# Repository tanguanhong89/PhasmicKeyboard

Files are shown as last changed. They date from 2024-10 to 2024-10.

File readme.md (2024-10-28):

# 1. Overview
Modular keyboard with adjustable key positions.

Uses `keebio/nyquist/rev3` vial keymap. 

## 1.1. Ortholinear mode
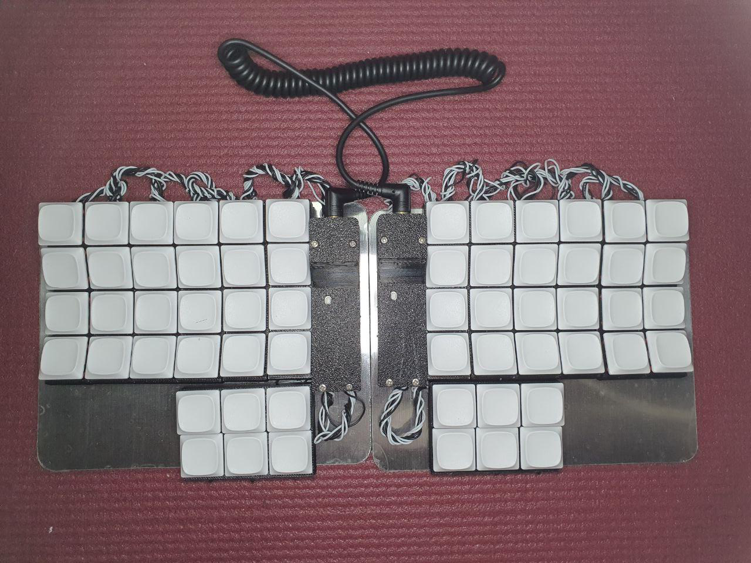
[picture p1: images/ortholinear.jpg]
Title


## 1.2. Column stagger mode
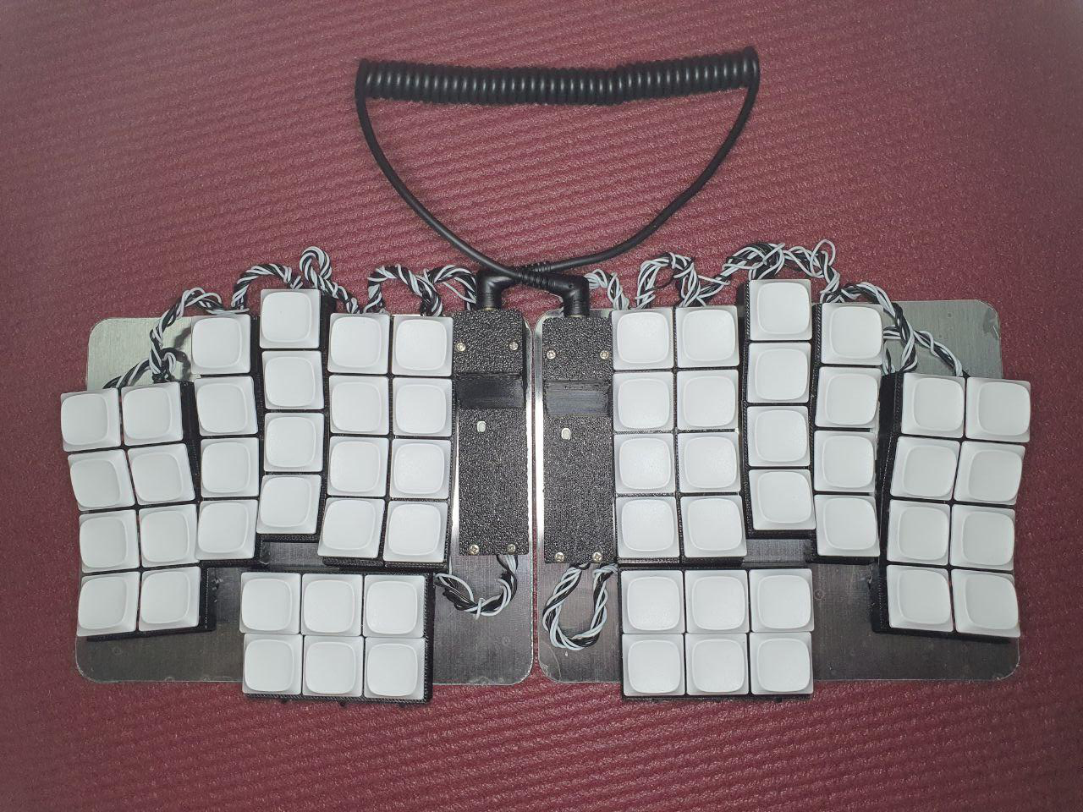
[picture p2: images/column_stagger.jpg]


## 1.3. WASD mode
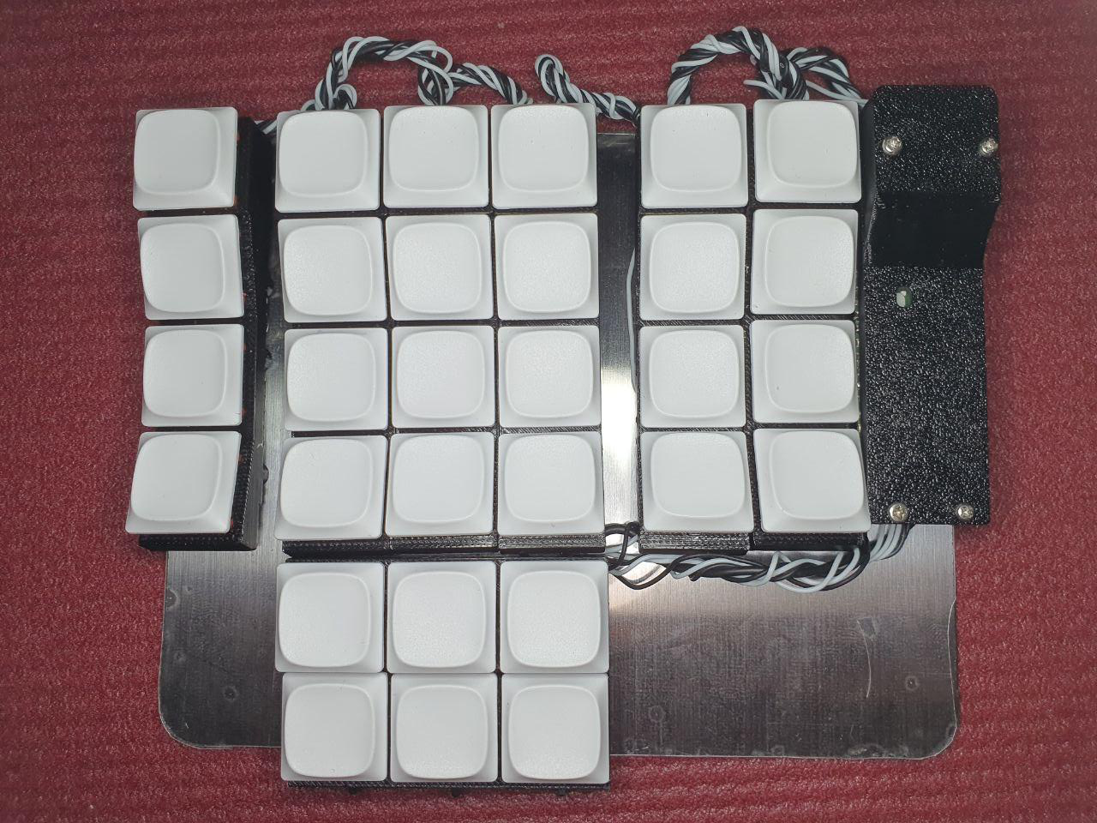
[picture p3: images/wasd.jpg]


## 1.4. Thumb cluster slide switches

So as to allow for toggling of those last 3 thumb cluster keys
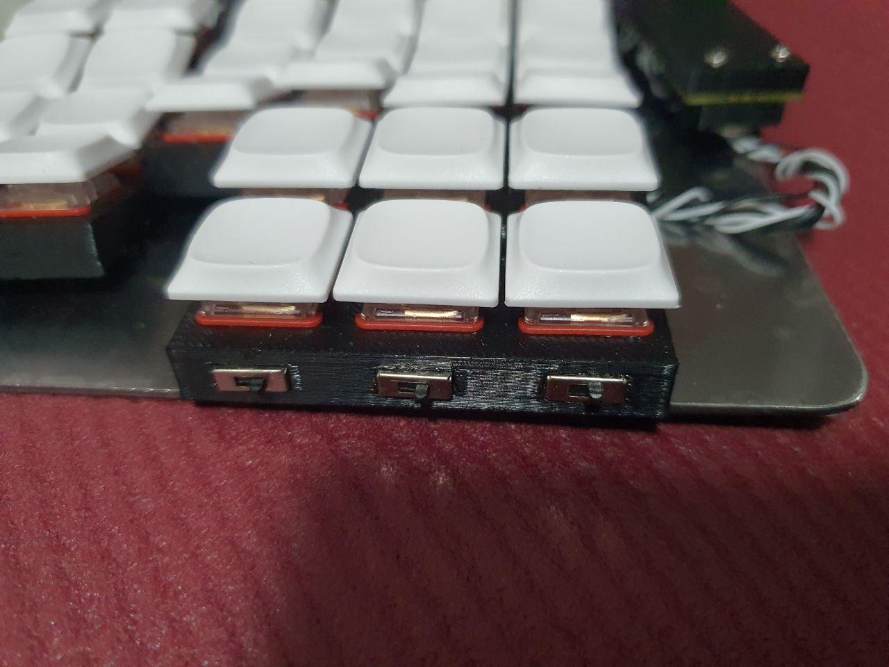
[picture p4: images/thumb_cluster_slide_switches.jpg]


## 1.5. Tilted column keys
2nd and 4th rows have 15 degrees tilted keys. This is for easier touch typing navigation along the y axis.
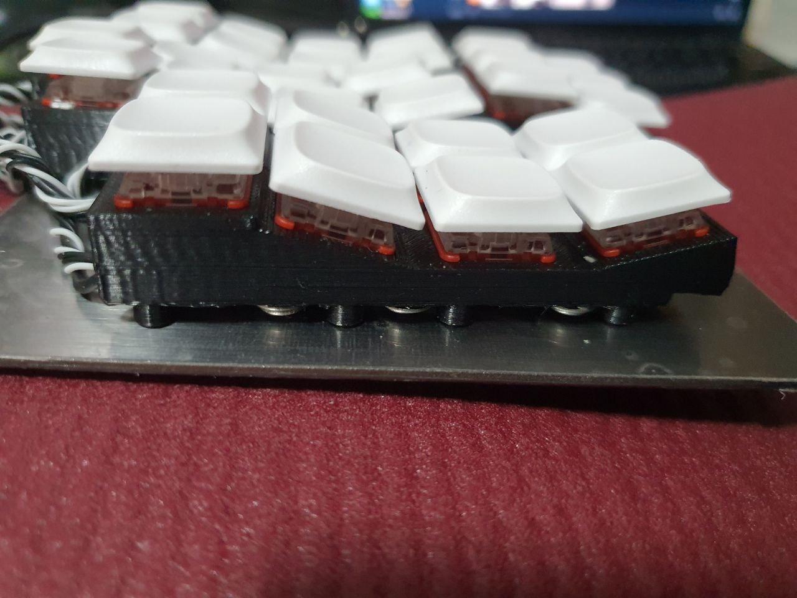
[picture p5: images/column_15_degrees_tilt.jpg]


## 1.6. Tenting with magnets
Additional magnets can be used for tenting the keyboard.
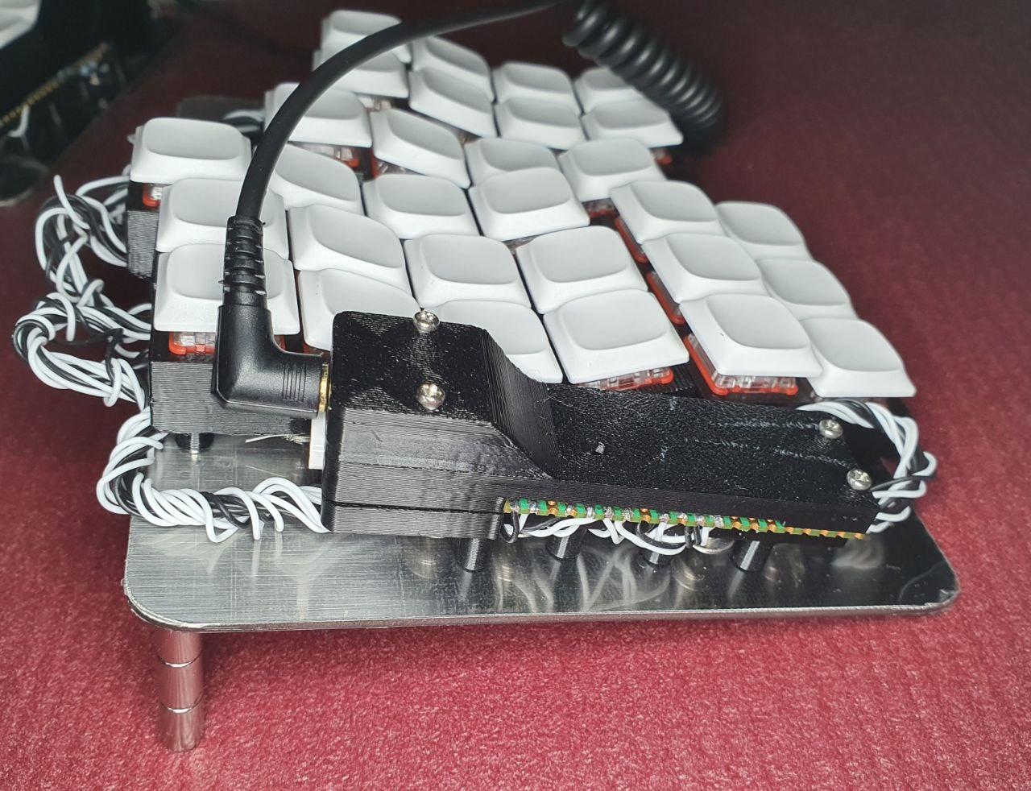
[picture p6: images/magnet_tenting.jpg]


# 2. Bill of materials
## 2.1. 3D models
- Column x 12
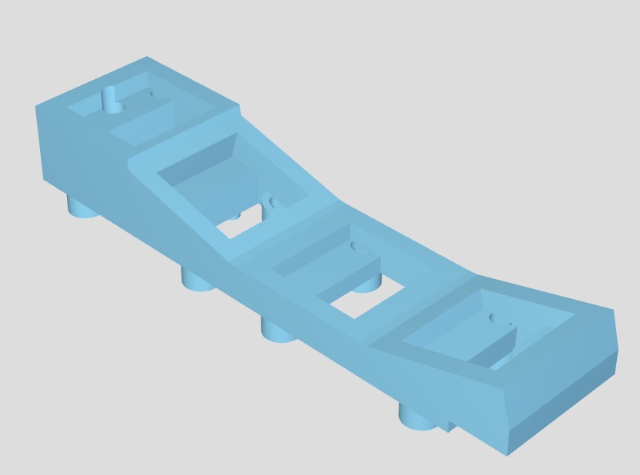
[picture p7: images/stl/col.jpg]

[An Internal Link](/stl/col.stl)
- Thumb cluster x 2
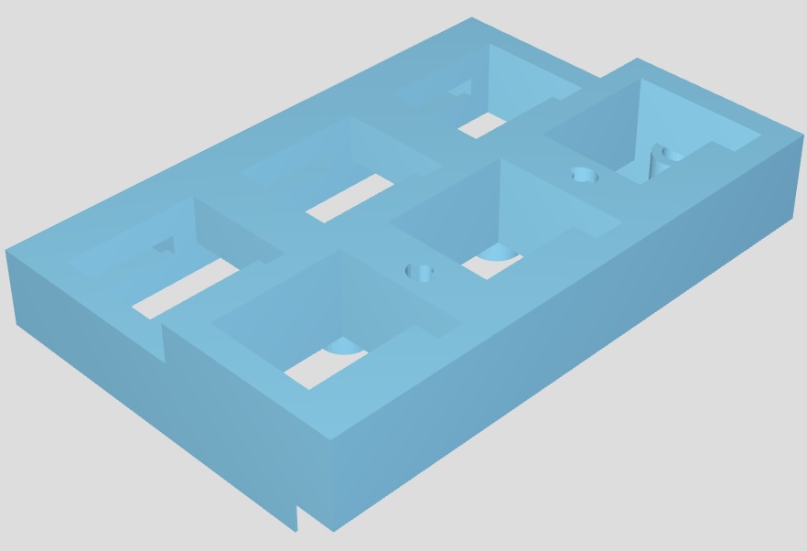
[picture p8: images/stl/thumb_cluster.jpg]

[An Internal Link](stl/thumb_cluster_2x3.stl)
- RP2040 pico housing bottom x 2
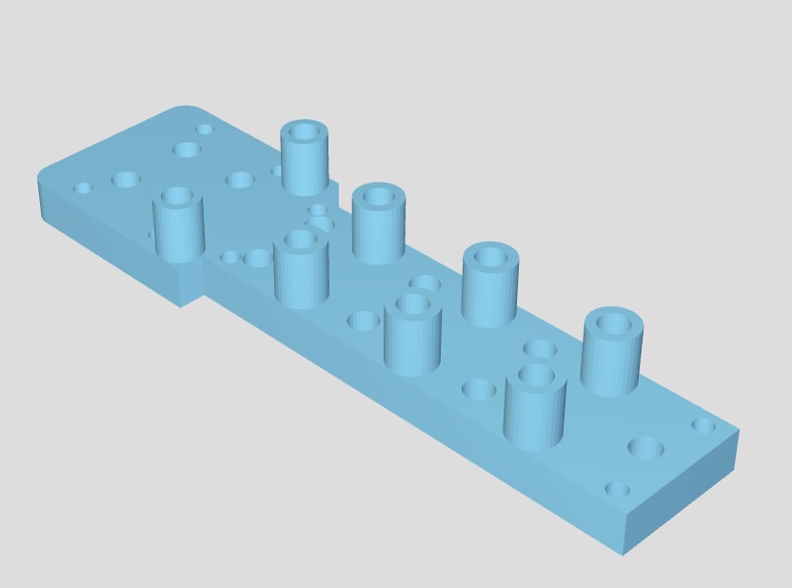
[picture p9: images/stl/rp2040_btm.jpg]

[An Internal Link](/stl/rp2040_pico_housing_btm.stl)
- RP2040 pico housing top x 2
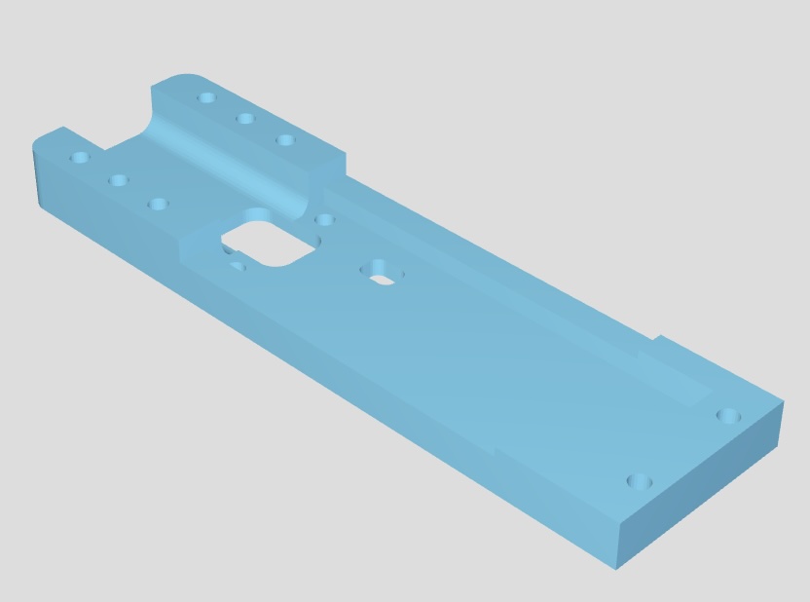
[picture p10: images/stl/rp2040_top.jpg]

[An Internal Link](/stl/rp2040_pico_housing_top.stl)
- RP2040 pico housing bottom x 2
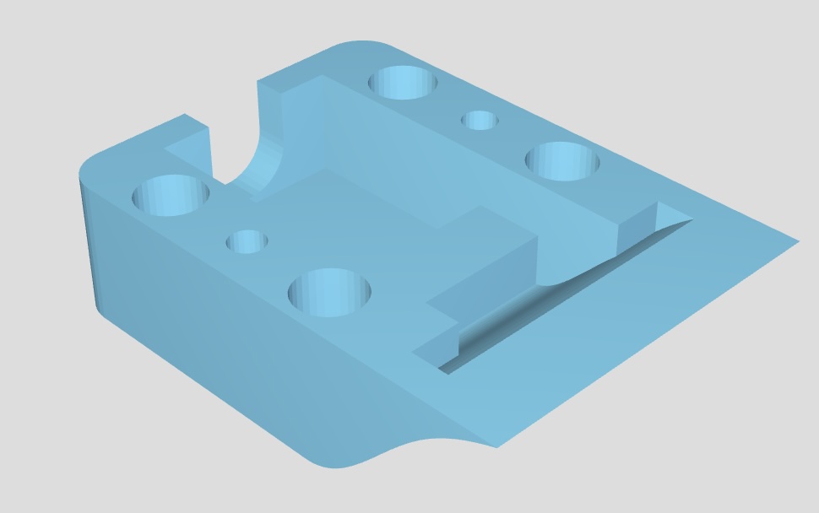
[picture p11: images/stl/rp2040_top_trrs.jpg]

[An Internal Link](/stl/rp2040_pico_housing_top_trrs.stl)

## 2.2. Others
- 124 x 
    - M3 screw x 5mm(threads)
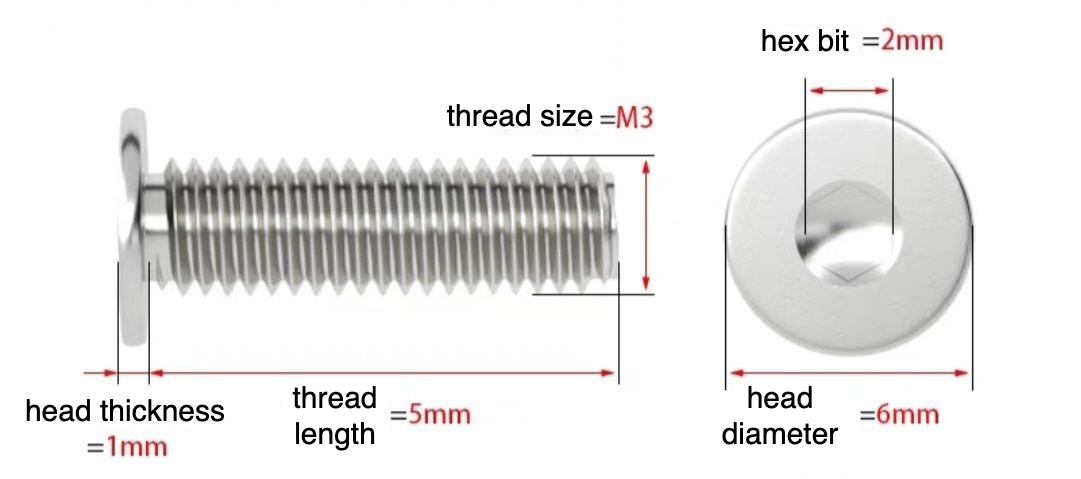
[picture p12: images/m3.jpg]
    
    - M3 washer x 8mm(radius) x 0.5mm(thickness)
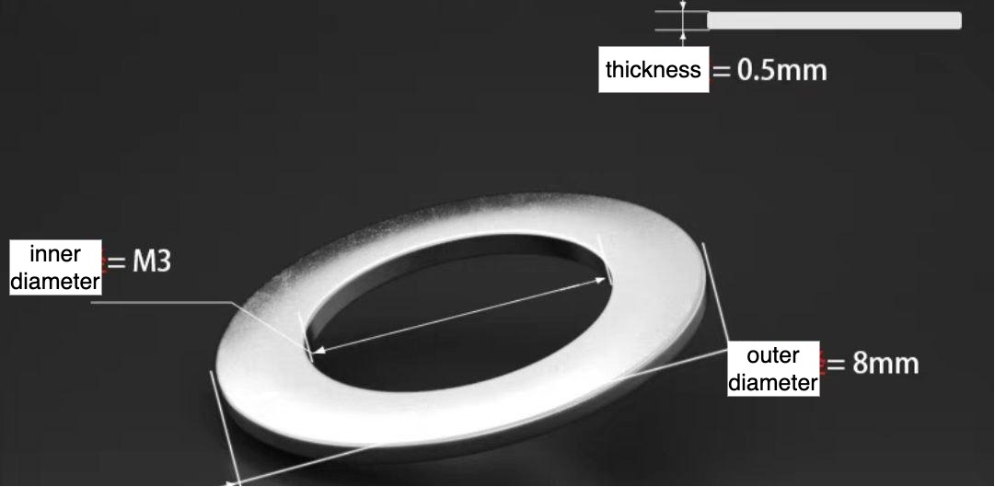
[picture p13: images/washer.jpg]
    

    Breakdown
    - 7(per column)x12(columns) +
    - 11(per rp2040 housing) x2(rp2040 housing) +
    - 9 (thumb cluster) x2(thumb cluster)

- 124 x magnets cylindrical N52 grade 3mm x 3mm
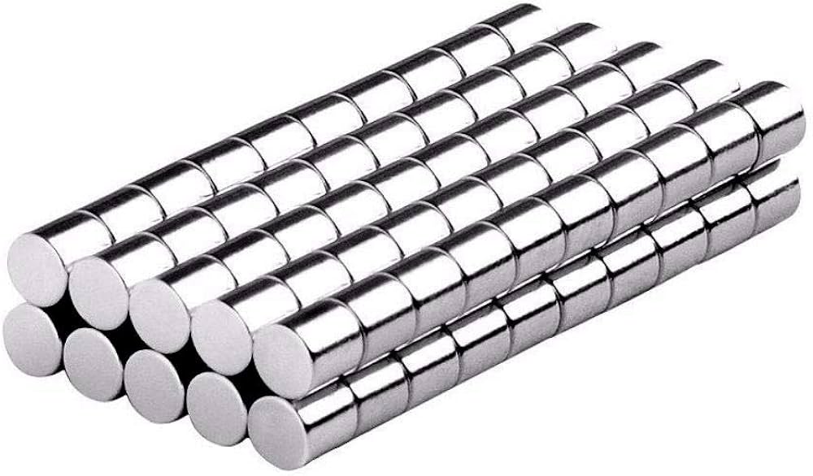
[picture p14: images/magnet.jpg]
    
- 60 x kailh choc v1 switches
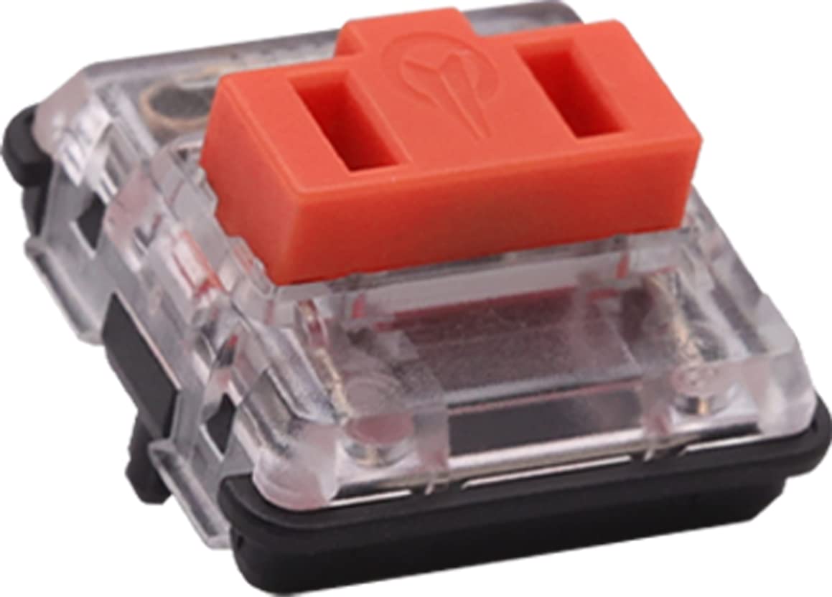
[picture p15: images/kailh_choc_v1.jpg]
    
- 60 x Geekark low profile keycaps for kailh choc v1 switches
    
- 60 x 1n4148 diodes
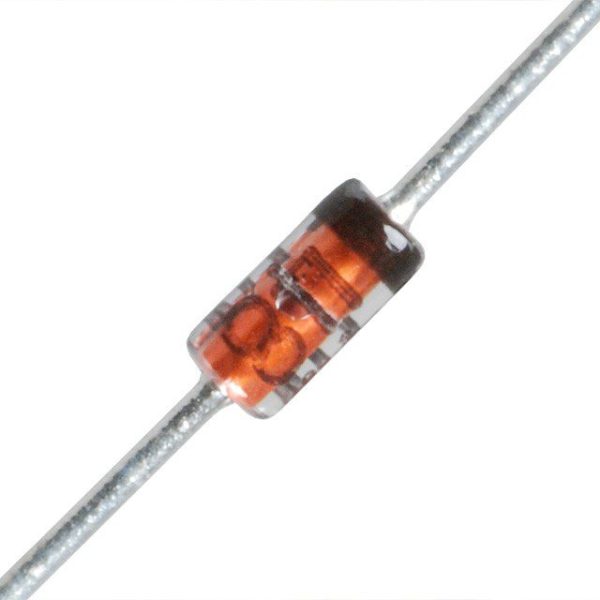
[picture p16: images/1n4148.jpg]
    
- 16 x M2 x 6mm (preferably torx)
- 4 x M2 x 10mm (preferably torx)
- 6 x SS12D00 (optional)
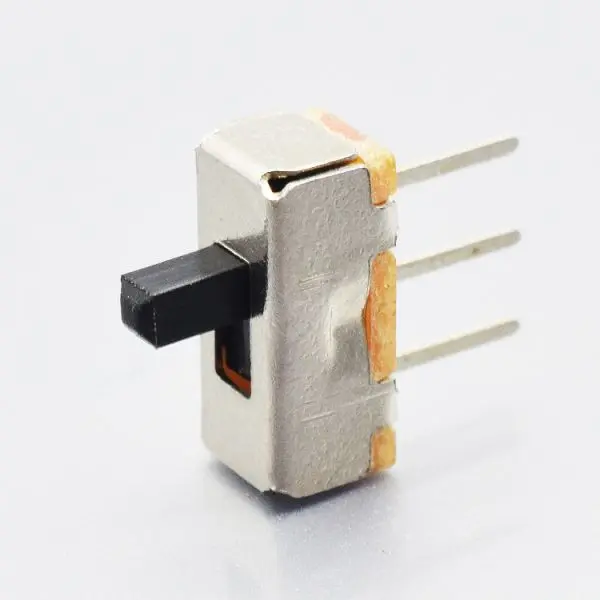
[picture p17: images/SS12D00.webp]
    
- 2 x RP2040 pico
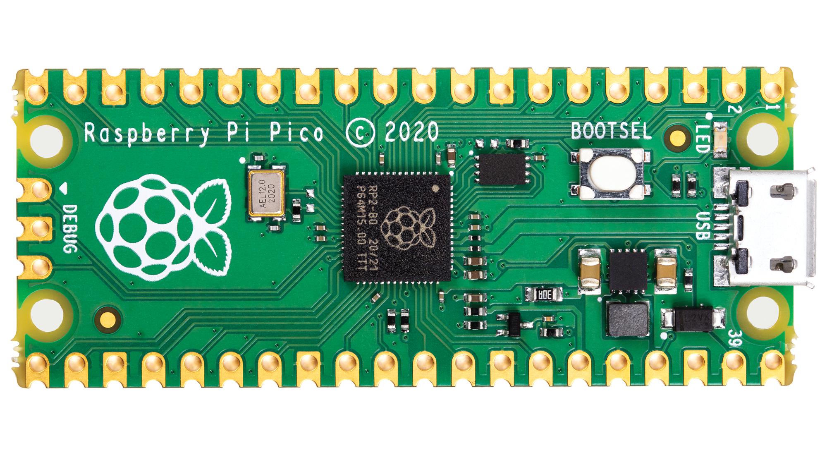
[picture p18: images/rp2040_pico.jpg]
    
- 2 x usb-c to micro-usb adapter
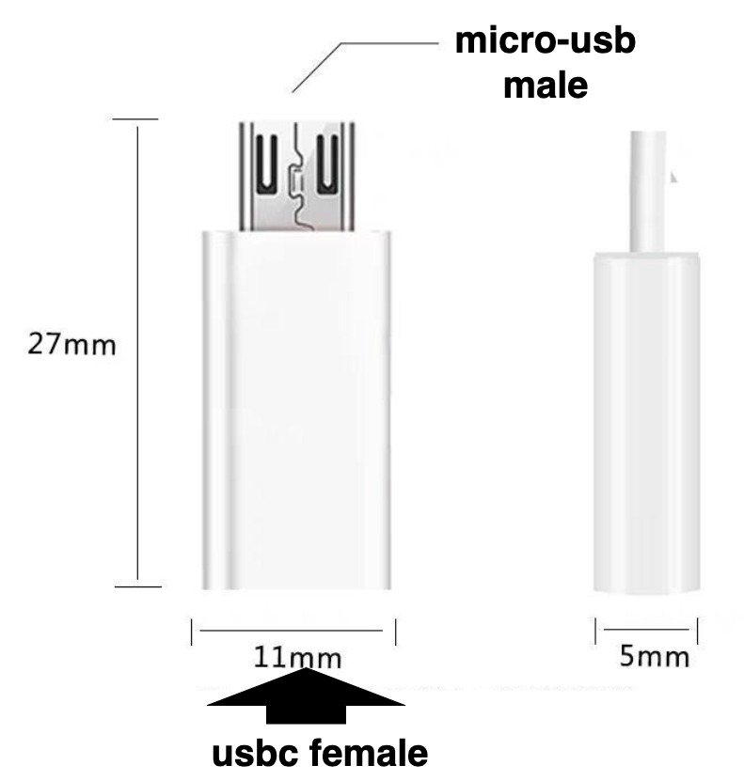
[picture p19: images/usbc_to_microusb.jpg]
    
- 2 x 430 grade steel plates(150mm x 120mm x 1.5mm thick)
- 1 x anti shatter film (to cover the steel plates)
- 1 x TRRS cable
- 1 x resistor (1kΩ-100kΩ range)
- 30 AUG wires (preferably more than 2 colors)
- 24 AUG wire (single color is enough)

# 3. Assembly
## 3.1. Fastening wires
One of the more efficient way to secure wire is to insert it through the M3 washer from 1 direction, then M3 screw from the opposite direction as shown below
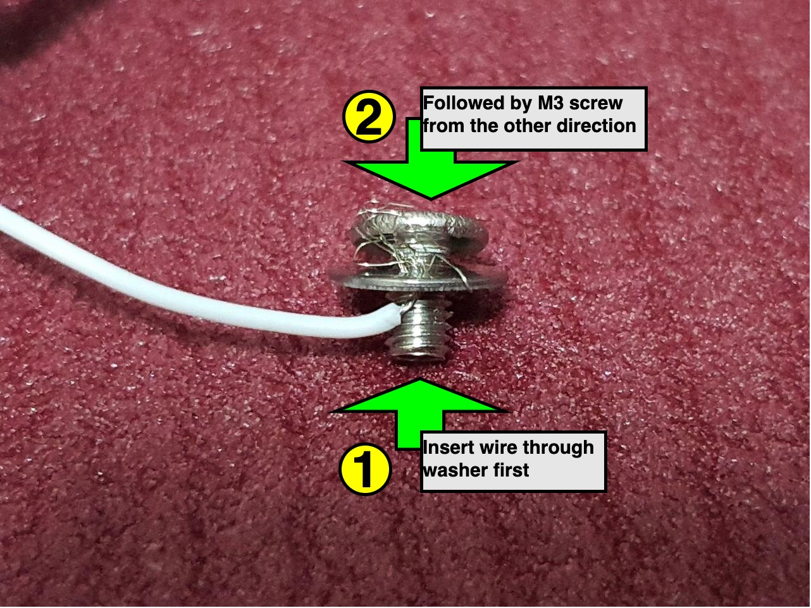
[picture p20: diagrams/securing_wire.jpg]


## 3.2. Preparing switches
48 switches are soldered with copper wires on the left pin. These switches are for the columns
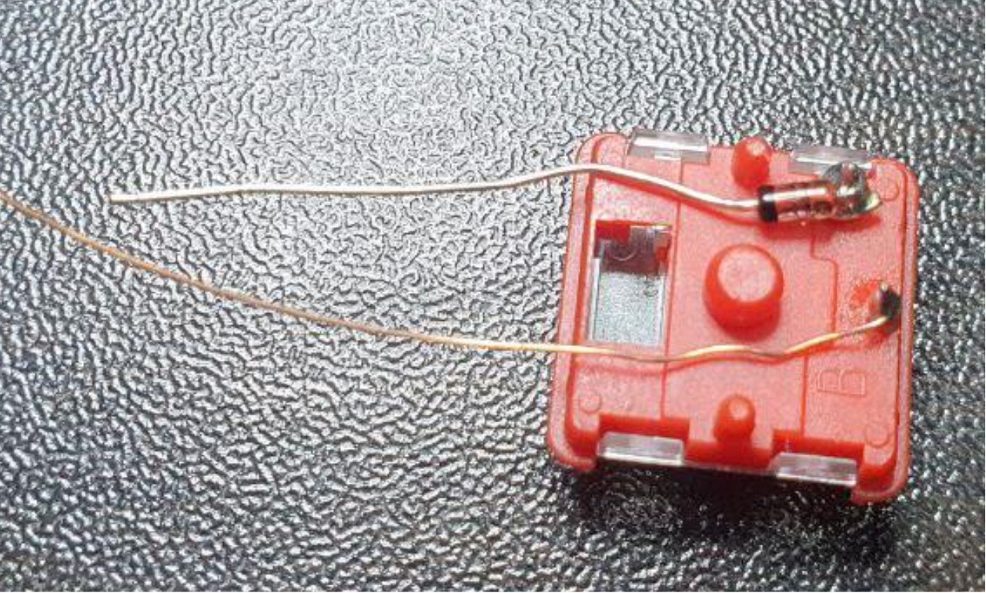
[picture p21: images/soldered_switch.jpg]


The remaining 12 switches are **soldered with 30 AUG insulated wires on the left pin** instead.

TODO add image

All switches are soldered with 1 1n4148 diode on the right pin, note the diode direction.
## 3.3. Magnets
Insert magnets with same facing poles into 3d printed parts on the same side (eg. all downward facing North pole to be on the left side of each column)

Repeat with opposite side with opposite facing pole

## 3.4. 430 Grade steel plates lamination
Laminating steel plates is not necessary, but recommended to ensure magnets slide smoothly on the plates, and also to prevent scratching and rust.

Cut the anti-shatter film by tracing loosely, the outline of the metal plate, with a pen knife.
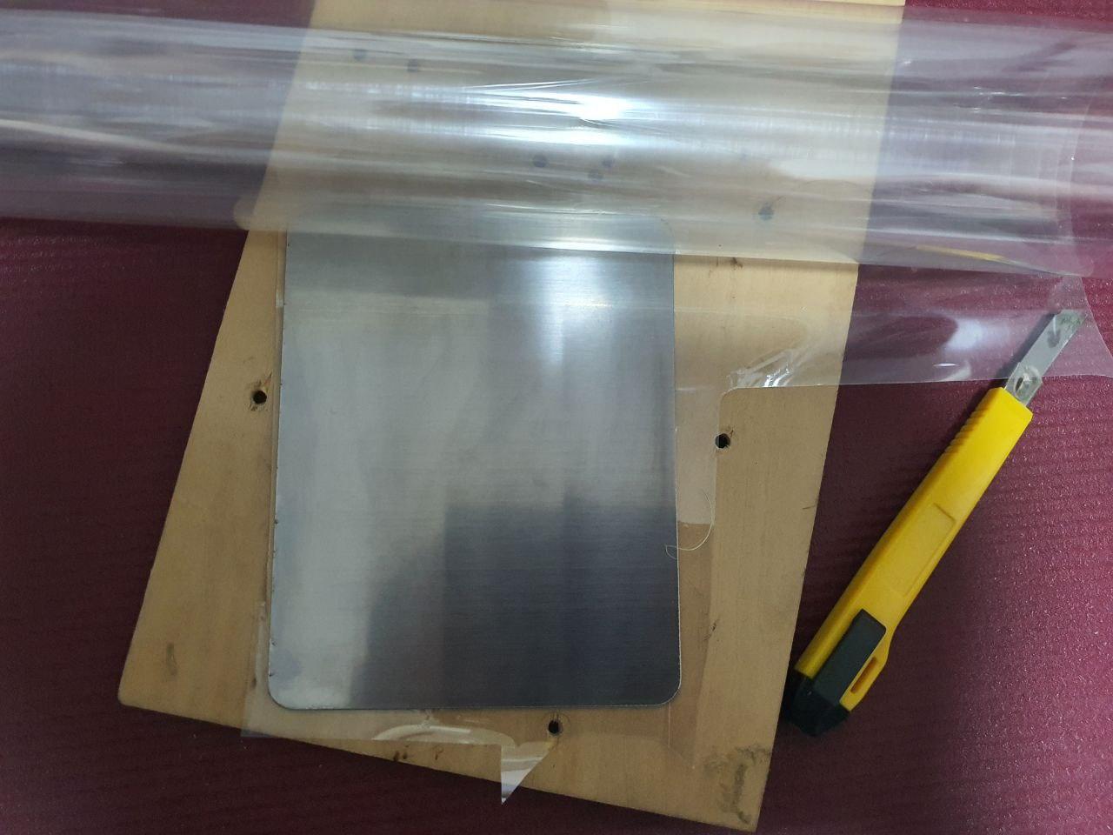
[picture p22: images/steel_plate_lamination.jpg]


Stick the film on the metal plate, then remove any excess film by tracing the metal plate more precisely. Cutting more precisely after sticking the film is easier as the film does not move around the plate.

## 3.5. Rows wiring
The row wires are supported by a single 24 AUG wire at row 1 that help resists pull tension.
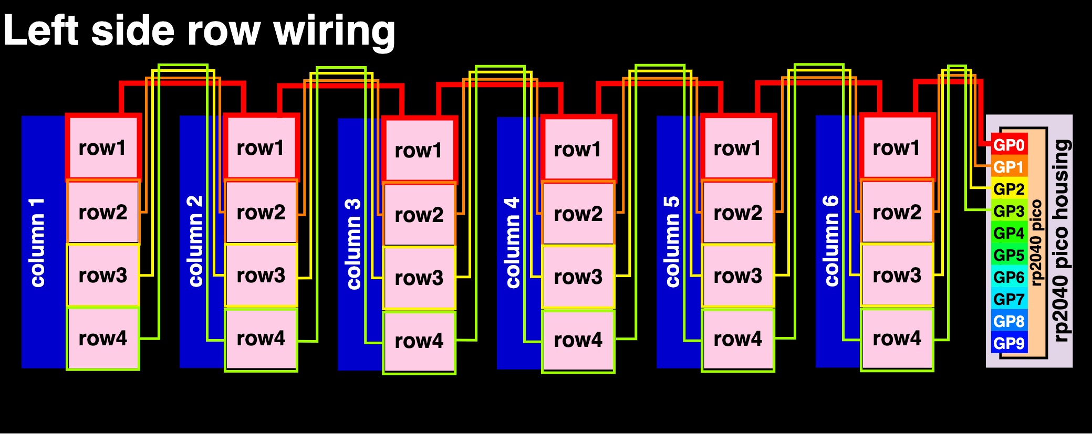
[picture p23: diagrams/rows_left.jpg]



- Starting with the first row,connect all 
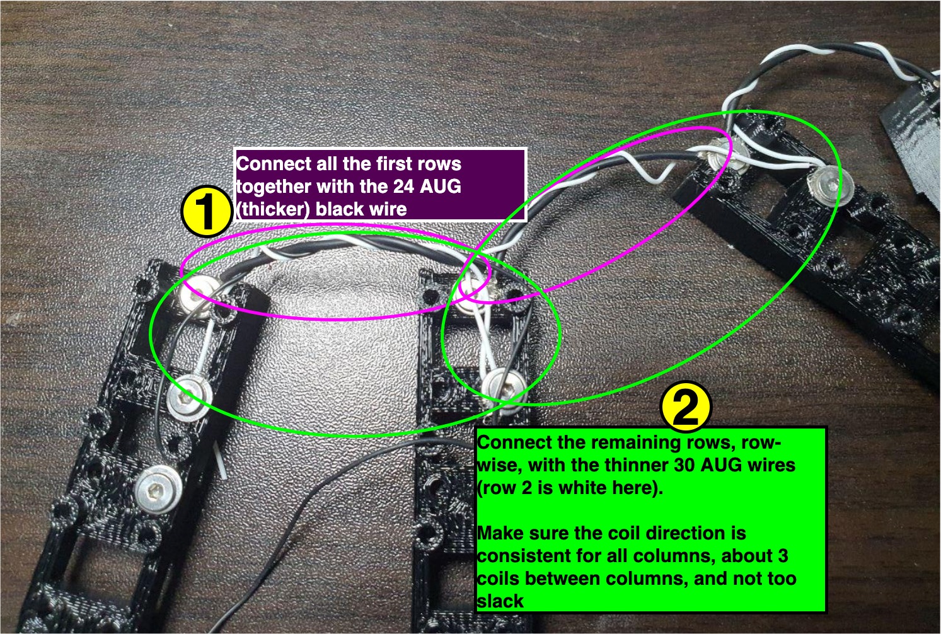
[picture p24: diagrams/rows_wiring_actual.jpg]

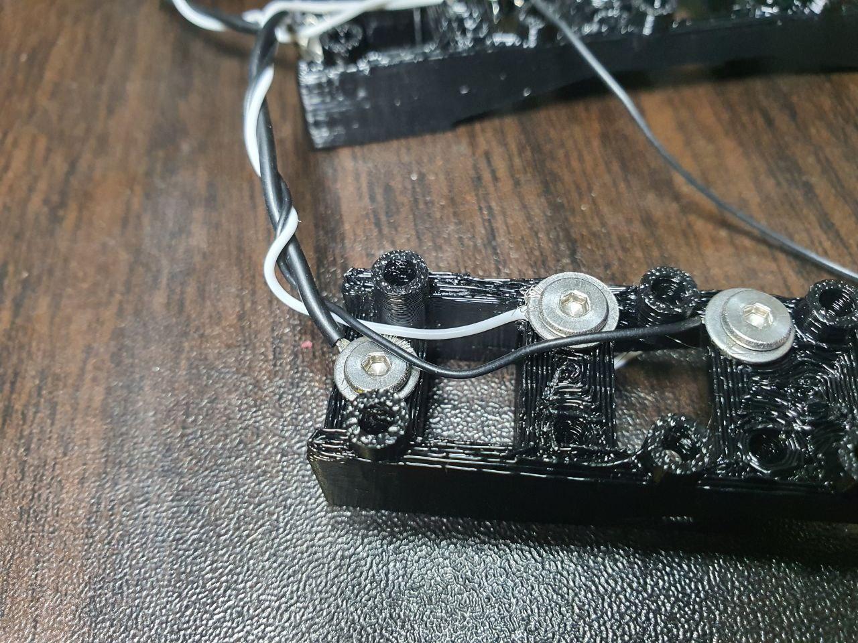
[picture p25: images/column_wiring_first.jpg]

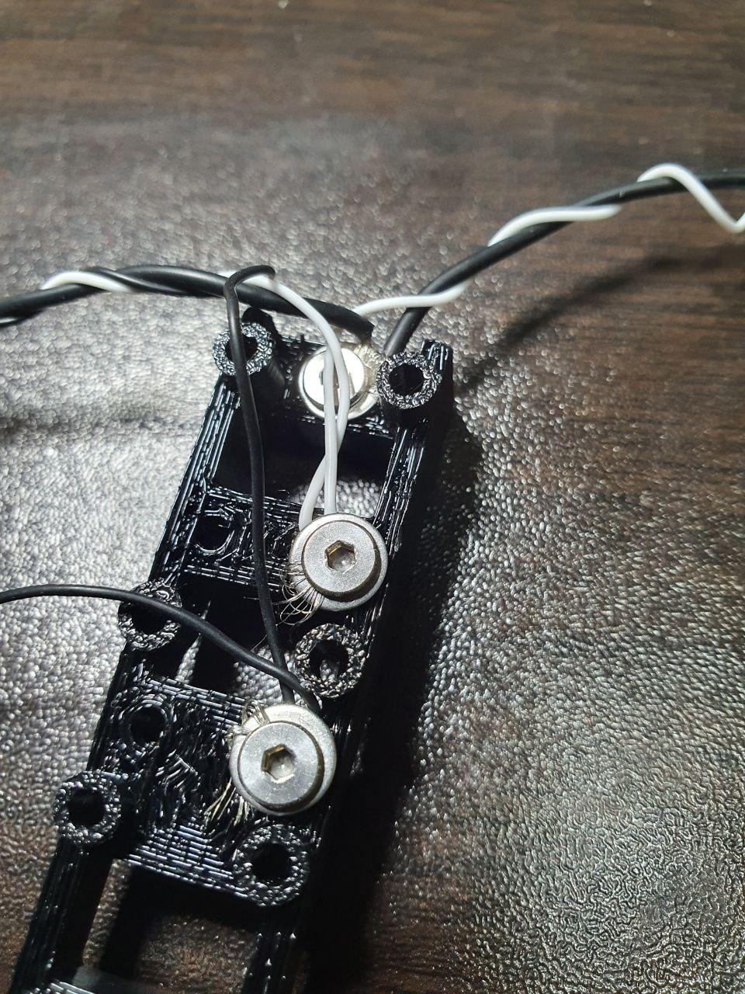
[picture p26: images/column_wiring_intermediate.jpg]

## 3.6. Thumb clusters wiring
Thumb clusters must be prepared before column wiring because each column wire on the RP2040 is connected to both the the column wires from the columns and also the thumb clusters.
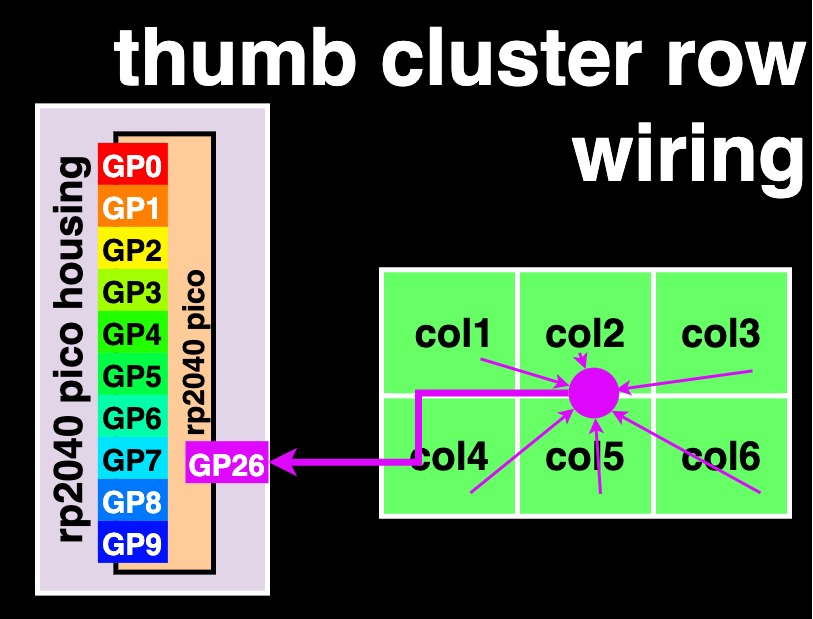
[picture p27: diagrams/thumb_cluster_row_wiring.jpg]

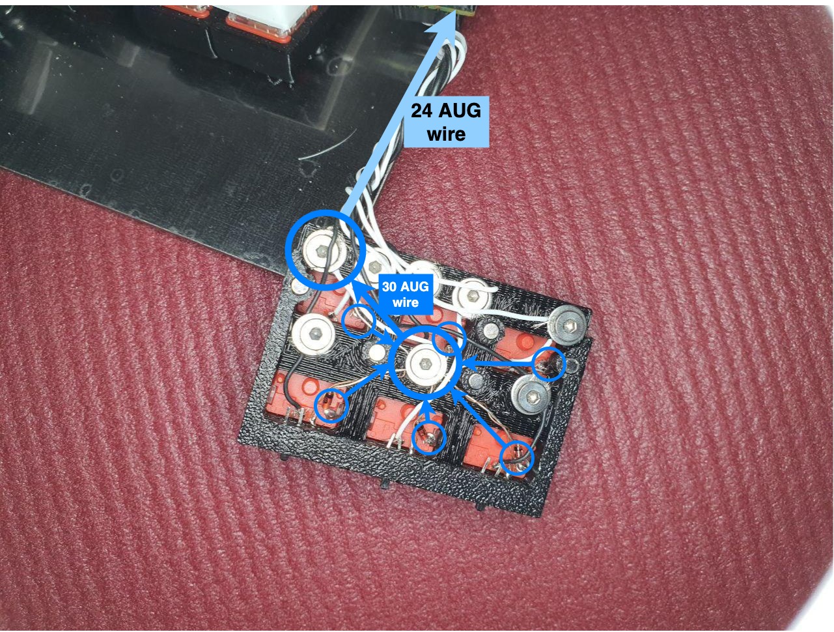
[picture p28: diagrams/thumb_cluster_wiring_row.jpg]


## 3.7. Columns wiring
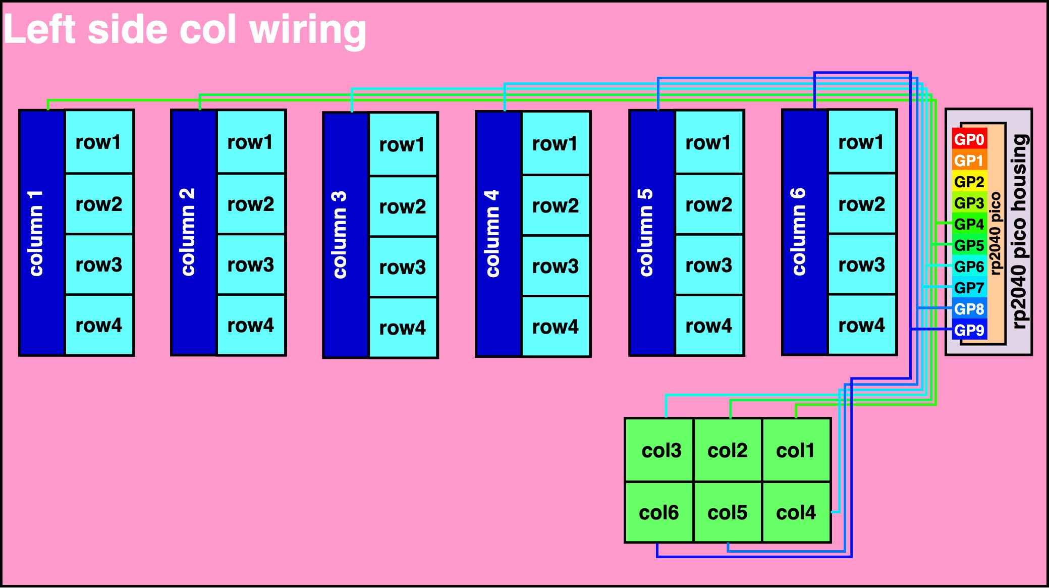
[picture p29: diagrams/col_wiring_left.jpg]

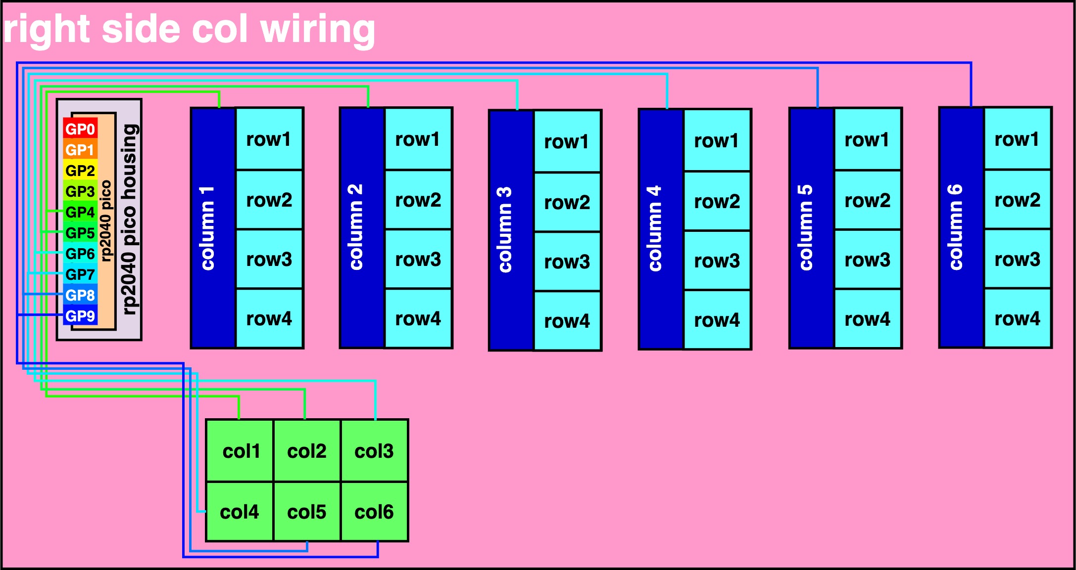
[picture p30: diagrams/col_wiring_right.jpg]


Column wires use 30 AUG sizes.

Lay the wires from the furthest to the closest.
- for left side, lay column 1 first then column 6 last.
- for right side, lay column 6 first, then column 1 last.

For each column pin hole on the RP2040, solder wires of the same column from the thumb cluster and the column housing together to the RP2040.

## 3.8. Securing column switches
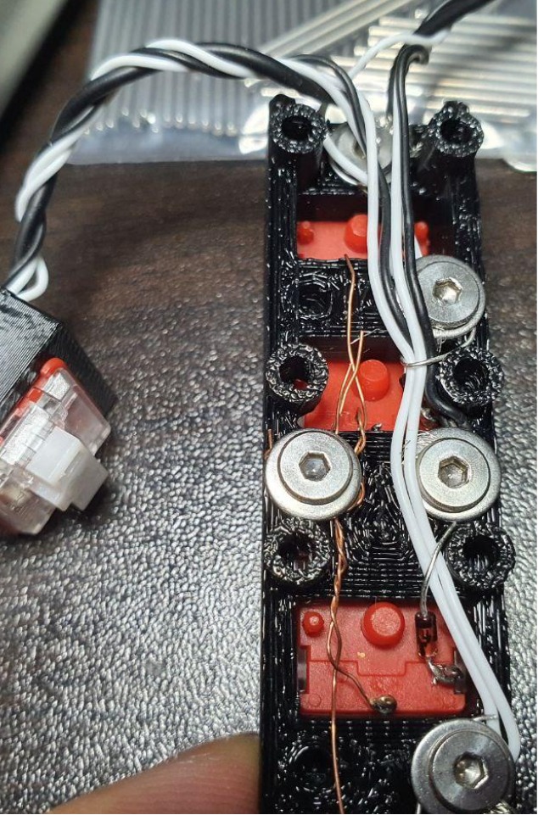
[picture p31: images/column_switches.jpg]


Secure the row wires with the switches' diodes, then secure the latter with the M3 screws and washers on the right side of the column housing as seen in the picture above. Note that each M3 screw on the right is also connected to its own row wire.

The column wiring is on the left of the column housing, which is a series of copper wires from the left pins of each switch secured together with another M3 screw and washer combo.

## 3.9. RP2040+adapter
Secure rp2040 pico and usbc adapter as follow:

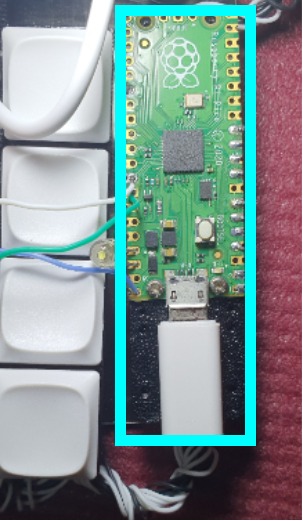
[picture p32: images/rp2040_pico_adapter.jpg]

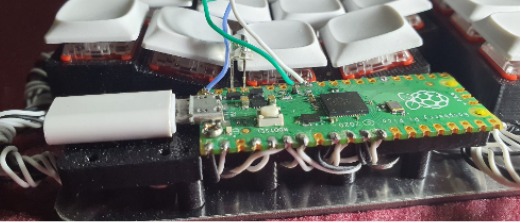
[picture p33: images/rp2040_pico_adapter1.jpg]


## 3.10. TRRS wiring
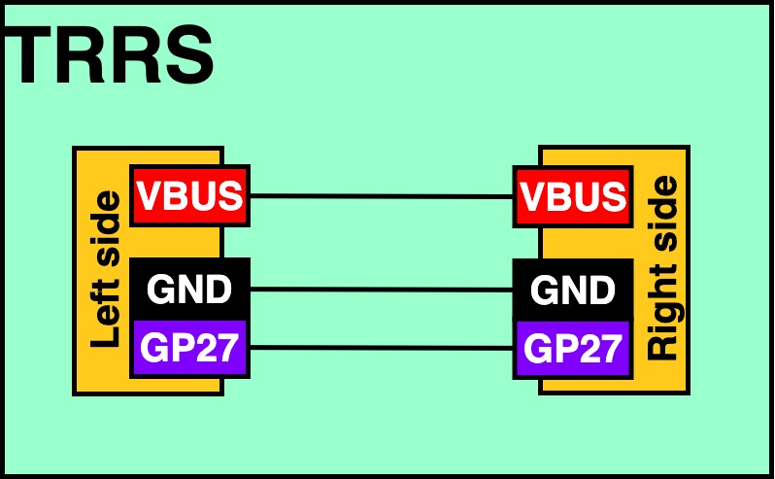
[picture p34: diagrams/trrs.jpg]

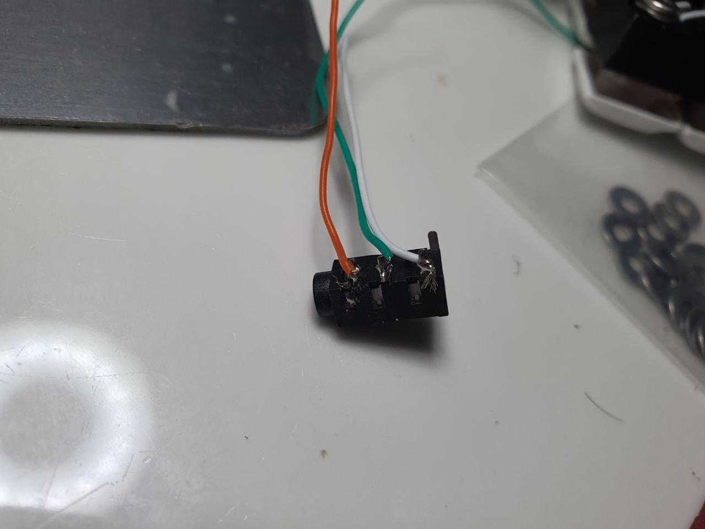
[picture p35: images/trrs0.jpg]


Secure TRRS wires with the extra pin so the wires do not come between TRRS and RP2040 top housing as follows:

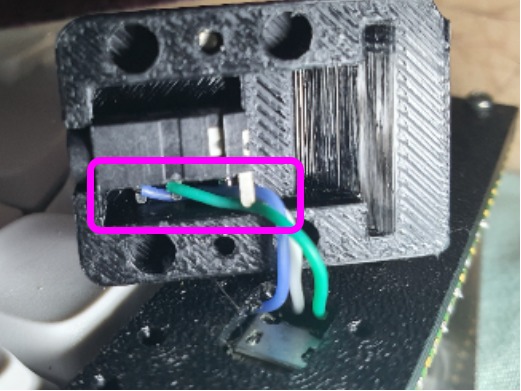
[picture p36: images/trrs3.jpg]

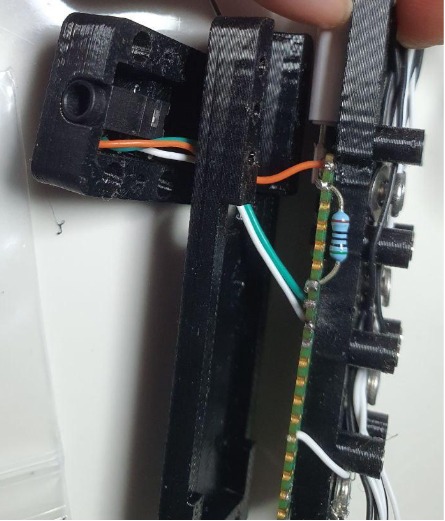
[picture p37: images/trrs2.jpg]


# 4. Flashing
Copy the keyboard settings to 

```
cp -R rev3/ somePath/keebio/nyquist/rev3
```
Then flash the firmware into the RP2040 controllers with the following command:
```
qmk flash -kb keebio/nyquist/rev3  -km vial  -e CONVERT_TO=promicro_rp2040
```

# 5. QMK Vial
Load keymap.vii into Vial

# 6. Fusion 360 CAD file
phasmic.f3d

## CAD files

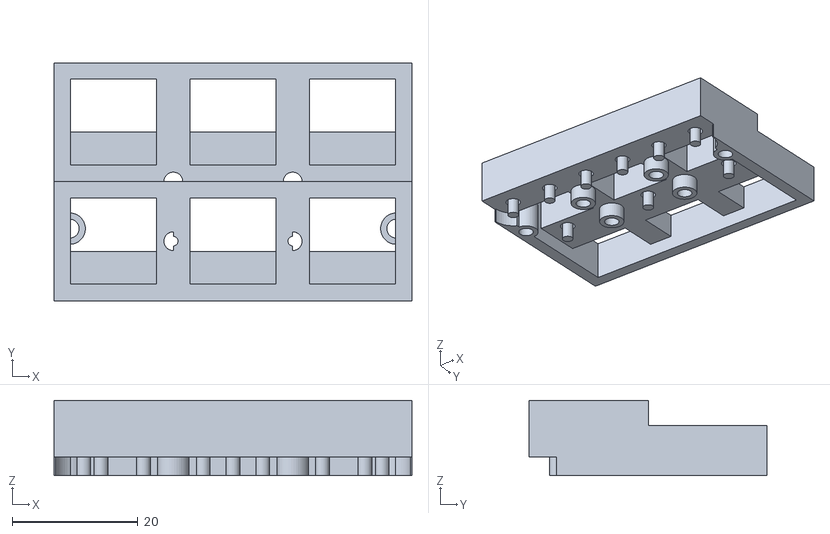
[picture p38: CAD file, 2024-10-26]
stl/thumb_cluster_2x3.stl
57.0 x 37.8 x 12.0

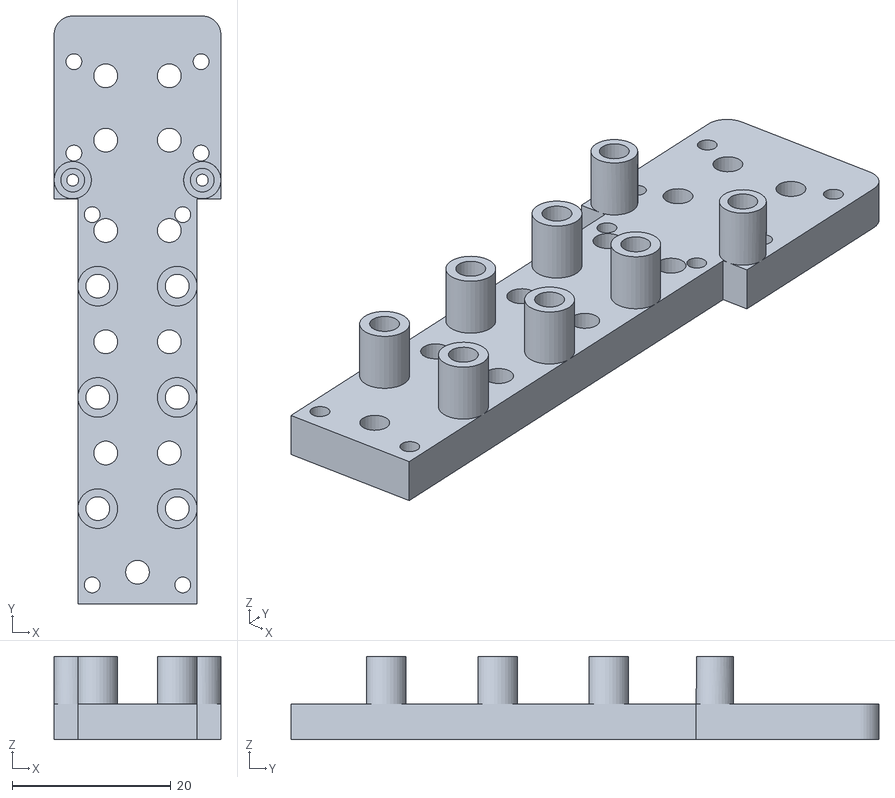
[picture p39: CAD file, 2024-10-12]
stl/rp2040_pico_housing_btm.stl
21.0 x 74.0 x 10.5

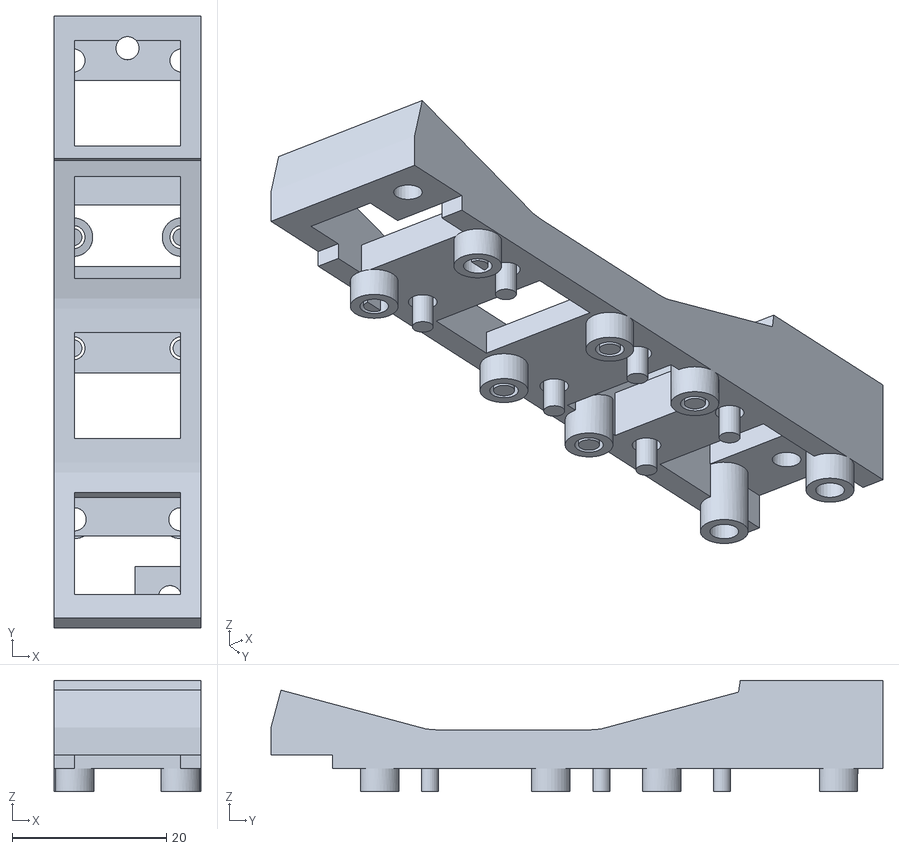
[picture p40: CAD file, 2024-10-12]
stl/col.stl
19.0 x 79.3 x 14.4

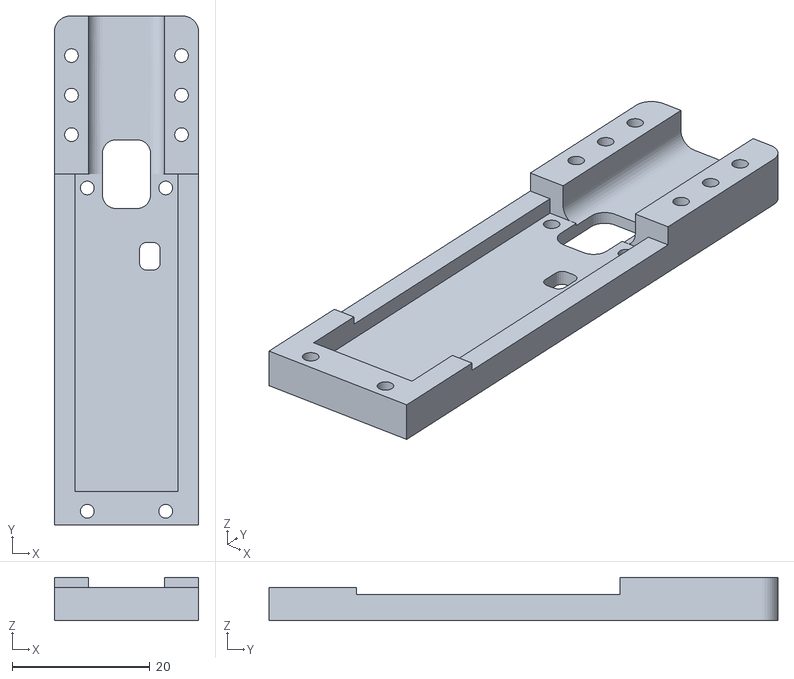
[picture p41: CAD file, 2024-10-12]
stl/rp2040_pico_housing_top.stl
21.0 x 74.0 x 6.30

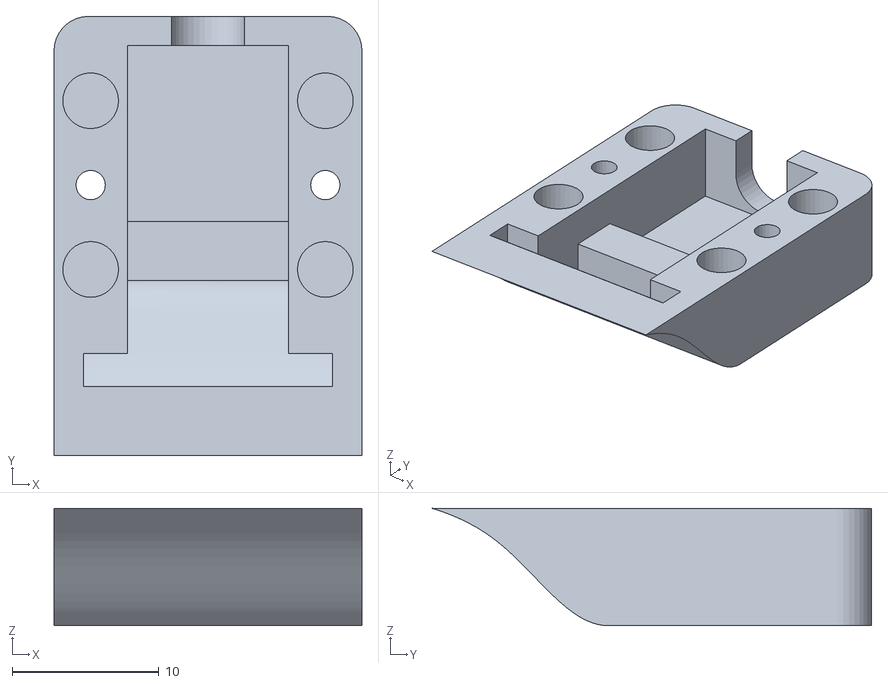
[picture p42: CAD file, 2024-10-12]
stl/rp2040_pico_housing_top_trrs.stl
21.0 x 29.9 x 8.00

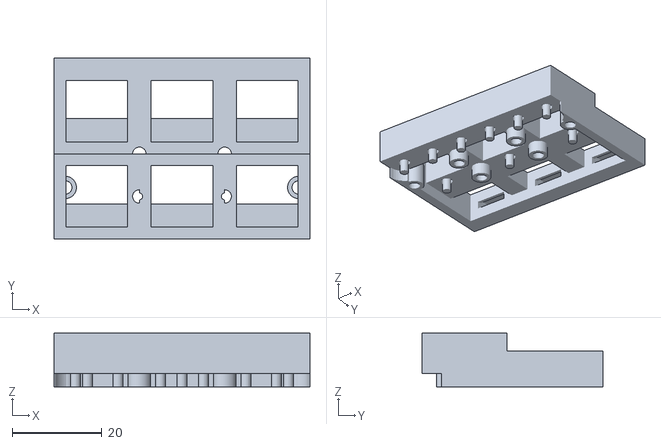
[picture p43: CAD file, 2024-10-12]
stl/thumb_cluster_2x3_with_slide_switches.stl
57.0 x 40.3 x 12.0

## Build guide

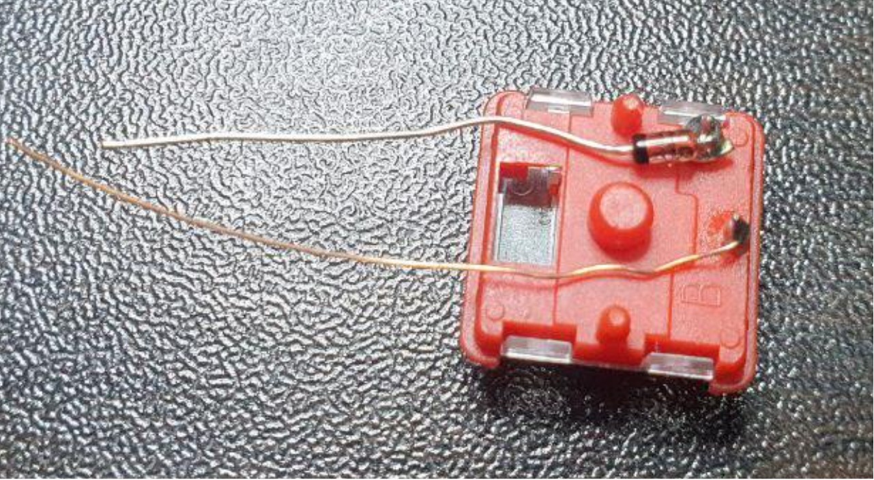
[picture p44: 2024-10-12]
images/kailh_choc_v1._soldered.jpg

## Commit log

2024-10-12 added bill of materials
    [rp2040_pico_housing_btm.stl]
2024-10-13 column wiring
2024-10-26 added thumb cluster without slide switches
    [thumb_cluster_2x3.stl, thumb_cluster_2x3_with_slide_switches.stl]
